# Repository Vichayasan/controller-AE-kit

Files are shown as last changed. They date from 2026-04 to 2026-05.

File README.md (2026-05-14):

# Controller AE Kit





---

## Table of Contents

1. [Project Introduction](#1-project-introduction)
2. [Project Objective](#2-project-objective)
3. [Background Theory: Acoustic Emission (AE) Sensing](#3-background-theory-acoustic-emission-ae-sensing)
4. [System Architecture](#4-system-architecture)
5. [Hardware List](#5-hardware-list)
6. [Design CAD](#6-design-CAD)
7. [Complete Wiring Diagram](#7-complete-wiring-diagram)
8. [Software Modules Explanation](#8-software-modules-explanation)
9. [Data Logging Output (CSV Format)](#9-data-logging-output-csv-format)
10. [Installation & Getting Started](#10-installation--getting-started)
11. [Project Timeline](#11-project-timeline)
12. [Timeline Summarize](#12-timeline-summarize)
13. [Contributors](#13-contributors)
14. [License & Ownership](#14-license--ownership)
15. [Note](#15-note)

---

## 1. Project Introduction

Mechanical seals are critical components widely used in rotating equipment such as pumps, compressors, and agitators within industrial facilities, particularly in the petrochemical and refinery sectors. Their primary function is to prevent the leakage of process fluids between the rotating shaft and the stationary housing, thereby ensuring safe and efficient plant operation.

Despite their essential role, mechanical seals are susceptible to progressive degradation caused by factors such as surface wear, thermal stress, chemical corrosion, and improper installation. When a seal begins to fail, microscopic cracks or surface discontinuities develop at the seal face, generating high-frequency elastic stress waves that propagate through the surrounding medium — a physical phenomenon known as Acoustic Emission (AE). If left undetected, even minor leakage can escalate into catastrophic failure, posing significant risks to personnel safety, environmental integrity, and equipment reliability.

This project presents the development of a real-time, embedded controller designed to acquire, process, and display Acoustic Emission signals originating from mechanical seal assemblies. The system is built upon the Cytron MOTION 2350 PRO microcontroller platform and is programmed entirely in MicroPython. It integrates a preamplified AE sensor, a graphical LCD display, a real-time clock (RTC) module, an encoder-based user interface, a buzzer alert system, and an RGB LED status indicator, forming a compact and self-contained condition monitoring kit suitable for field deployment.

---

## 2. Project Objective

The objectives of this project are as follows:

1. To develop a firmware-based embedded controller capable of acquiring Acoustic Emission signals from a mechanical seal assembly in real time.
2. To implement a signal processing pipeline in MicroPython that filters and evaluates AE signal amplitude against predefined threshold levels.
3. To design a user-friendly graphical interface on the MKS-MINI12864-V3 LCD display, allowing operators to monitor seal condition and configure detection parameters on-site.
4. To integrate a real-time clock (RTC) module for timestamping detection events, enabling traceability and post-incident analysis.
5. To provide audible and visual alert outputs — via a piezoelectric buzzer and NeoPixel RGB LED — to notify operators of abnormal AE activity indicative of seal leakage.
6. To validate the complete system through bench-level testing, verifying signal acquisition accuracy, threshold responsiveness, and display functionality.

---

## 3. Background Theory: Acoustic Emission (AE) Sensing

### 3.1 What is Acoustic Emission?

Acoustic Emission (AE) is a phenomenon in which transient elastic waves are generated by the rapid release of localized energy within a material. This energy release typically originates from micro-scale events such as crack initiation and propagation, plastic deformation, friction between sliding surfaces, impact, or fluid leakage through narrow gaps.

In the context of mechanical seal monitoring, AE signals are primarily produced by two mechanisms:

- **Solid-borne friction:** When the lapped faces of a degraded seal make irregular contact, micro-asperities on opposing surfaces collide and generate stress waves at frequencies typically ranging from **100 kHz to 1 MHz**.
- **Fluid-borne leakage:** When pressurized process fluid escapes through a compromised seal gap, turbulent flow and cavitation at the orifice generate broadband AE activity detectable at the seal housing.

Unlike vibration monitoring (which operates in the 10 Hz – 10 kHz range), AE sensing detects events at ultrasonic frequencies that are entirely inaudible to humans and undetectable by conventional accelerometers, making it uniquely sensitive to early-stage seal deterioration.

### 3.2 AE Signal Characteristics

A typical AE signal observed from a leaking mechanical seal exhibits the following characteristics:

| Parameter | Description |
|---|---|
| **Frequency Range** | 100 kHz – 1 MHz (ultrasonic) |
| **Signal Type** | Continuous or burst emission |
| **Key Feature** | Voltage amplitude correlates with leak severity |
| **Propagation** | Travels through solid structures as longitudinal or shear waves |

The most commonly used signal feature for leak detection is the voltage amplitude read from the preamplifier output, which represents the energy content of the AE signal at each sampling instant. An increase in amplitude beyond a calibrated threshold is a reliable indicator of abnormal friction or leakage activity at the seal face.

### 3.3 Preamplifier Role

Raw AE signals from piezoelectric sensors are extremely weak (typically in the microvolt range) and broadband. A dedicated **preamplifier** is therefore placed as close to the sensor as possible to:

1. Amplify the signal to a measurable voltage range (typically by 40–60 dB).
2. Apply bandpass filtering to reject low-frequency mechanical noise and retain only the AE frequency band of interest.
3. Improve the signal-to-noise ratio (SNR) before the signal is transmitted to the microcontroller's ADC input.

In this system, the preamplifier output is connected directly to an analog input pin of the MOTION 2350 PRO, where it is sampled and processed by the firmware.

---

## 4. System Architecture

The overall system consists of four functional layers: **sensing**, **processing**, **output/display**, and **user interaction**. The data flow is described as follows:

```
┌─────────────────────────────────────────────────────────────────┐
│                        SENSING LAYER                            │
│   AE Piezoelectric Sensor → Preamplifier (preamp_mod.py)        │
│   Analog signal → ADC on MOTION 2350 PRO (GP26, GP27)           │
└────────────────────────────┬────────────────────────────────────┘
                             │
┌────────────────────────────▼────────────────────────────────────┐
│                      PROCESSING LAYER                           │
│   config.py     → System-wide pin assignments and constants     │
│   preamp_mod.py → ADC sampling, circular buffer, waveform draw  │
│   rtc_mod.py    → Timestamp acquisition via DS3231 RTC          │
└────────┬───────────────────┬────────────────────────────────────┘
         │                   │
┌────────▼──────────┐  ┌─────▼──────────────────────────────────┐
│   OUTPUT LAYER    │  │           USER INTERFACE LAYER         │
│ beeper_mod.py     │  │  encoder_mod.py  → Rotary input        │
│ neopixel_mod.py   │  │  lcd_mod.py      → Graphical display   │
│ (buzzer + LED     │  │  ST7567driver.py → LCD low-level driver│
│  heartbeat)       │  │  (MKS-MINI12864-V3)                    │
└───────────────────┘  └────────────────────────────────────────┘
                                        │
                             ┌──────────▼──────────┐
                             │    SD CARD LOGGING  │
                             │  CSV file via SPI   │
                             │  (PIN_SD_CS = GP17) │
                             └─────────────────────┘
```

All modules are coordinated through `config.py`, which stores shared parameters such as ADC pin assignments, SPI/I2C settings, and timing constants, ensuring a clean and maintainable firmware architecture.

---

## 5. Hardware List

The following hardware components are used in this project:

| # | Component | Model | Role |
|---|---|---|---|
| 1 | Microcontroller | Cytron MOTION 2350 PRO | Main processing unit (RP2350 dual-core) |
| 2 | AE Sensor | Piezoelectric AE Sensor | Detects ultrasonic elastic waves from seal |
| 3 | Preamplifier | AE Preamplifier Module | Amplifies and filters raw AE signal |
| 4 | Graphical LCD | MKS-MINI12864-V3 (ST7567 driver) | Displays real-time waveform and UI |
| 5 | Real-Time Clock | DS3231 RTC Module | Provides accurate timestamp for CSV logging |
| 6 | Rotary Encoder | Incremental Encoder with button | User interface navigation |
| 7 | Buzzer | Piezoelectric Buzzer | Non-blocking audible feedback |
| 8 | RGB LED | NeoPixel WS2812B (×3) | Heartbeat and status indicator |
| 9 | SD Card Module | SPI SD Card | Stores CSV data log files |
| 10 | Power Supply | 5V DC / USB | Powers the controller board |

### Microcontroller: Cytron MOTION 2350 PRO

The Cytron MOTION 2350 PRO is a feature-rich robotics and automation controller based on the Raspberry Pi **RP2350** chip (dual-core Arm Cortex-M33, up to 150 MHz). It provides multiple GPIO pins, hardware I2C/SPI/UART interfaces, 12-bit ADC inputs, and native MicroPython support, making it well-suited for real-time embedded sensor applications.

> Reference: [Cytron MOTION 2350 PRO GitHub](https://github.com/CytronTechnologies/Cytron-MOTION-2350-PRO)

### Display: MKS-MINI12864-V3

The MKS-MINI12864-V3 is a compact 128×64 pixel graphical LCD module driven by the ST7567 controller chip, communicating via SPI. It provides a clear monochrome display sufficient for rendering real-time AE signal waveforms, voltage readouts, and menu navigation.

> Reference: [MKS-MINI12864-V3 GitHub](https://github.com/makerbase-mks/MKS-MINI12864-V3)

### RTC: DS3231

The DS3231 is a highly accurate I2C real-time clock module with a built-in temperature-compensated crystal oscillator (TCXO), ensuring timekeeping accuracy of ±2 ppm across a wide temperature range. It is used in this project to timestamp each CSV log entry, supporting post-analysis and maintenance record-keeping.

---
## 6. Design CAD

The mechanical enclosure of the Acoustic Emission (AE) Controller Kit was designed using 3D Computer-Aided Design (CAD) software to ensure durability, field-readiness, and ergonomic operation. The structural layout incorporates specific geometric features aimed at protecting internal components while facilitating user interaction and system maintenance.

### User Interface and Control Accessibility
* **LCD Display:** The enclosure features a flush-mounted rectangular cutout designed specifically for the LCD screen, allowing the display to align seamlessly with the exterior surface.
* **Rotary Encoder:** A dedicated aperture is provided for the rotary encoder knob, enabling precise parameter adjustments and system navigation.
* **Reset Button:** To facilitate system reboots, a precisely drilled hole allows direct access to the reset button.
* **Component Protection:** Recessed rectangular slots are engineered for both the main switch and the AMC channel ports, providing a physical buffer that mitigates the risk of accidental actuation or impact damage to the connectors.
* **Data Access:** An external rectangular port is integrated to permit SD card insertion and data retrieval without requiring the disassembly of the main housing.

### Structural Integrity and Assembly
* **Chassis Mounting:** To ensure structural rigidity, multiple mounting holes are distributed across the enclosure, utilizing heat-set threaded inserts to securely fasten the primary internal frame. Additional heat-set insert points are strategically positioned on both lateral sides to further reinforce the chassis assembly against operational vibrations.
* **Portability:** For enhanced portability and operational safety, specific holes equipped with heat-set inserts serve as secure anchor points for an external hand strap.

### Ergonomics and Power Management
* **Kickstand Integration:** The posterior section of the enclosure incorporates extruded housings and slotted grooves specifically designed to accommodate a deployable kickstand. This integration allows the device to be elevated at an optimal viewing angle during stationary operation.
* **Battery Retention:** The power management section features a dedicated rectangular cutout functioning as a battery locking mechanism. This is supplemented by elongated flat slots designed for routing cable ties or straps, ensuring the battery pack remains securely immobilized during field transit.





---
## 7. Complete Wiring Diagram

### AE Sensor Wiring

The AE sensor is connected to the preamplifier input, and the preamplifier analog output is routed to the ADC-capable GPIO pins on the MOTION 2350 PRO. The system supports **two independent AE sensors** simultaneously:

- **AE Sensor 01** → GP26 (`PIN_AE_SENSOR01_ADC`)
- **AE Sensor 02** → GP27 (`PIN_AE_SENSOR02_ADC`)

- Hardware connection wiring — **AE sensor**


### MKS-MINI12864-V3 to MOTION 2350 PRO GPIO Pinout

The LCD and SD card share the same SPI bus. The following pin mapping is used:

| Signal | MOTION 2350 PRO GPIO | Description |
|---|---|---|
| SPI SCK | GP18 | SPI Clock (LCD + SD card shared) |
| SPI MOSI | GP19 | SPI Data out |
| SPI MISO | GP16 | SPI Data in (SD card read) |
| LCD CS | GP2 | LCD Chip Select |
| LCD DC | GP3 | LCD Data/Command Select |
| LCD RST | GP1 | LCD Reset |
| SD CS | GP17 | SD Card Chip Select |
| RTC SDA | GP28 | RTC I2C Data |
| RTC SCL | GP29 | RTC I2C Clock |
| NeoPixel | GP4 | RGB LED Data |
| Buzzer | GP0 | PWM Buzzer |
| Encoder A | GP5 | Encoder Channel A |
| Encoder B | GP6 | Encoder Channel B |
| Encoder BTN | GP7 | Encoder Push-Button |

> **Note:** All pin assignments above are defined in `config.py`. Verify against your specific board revision before assembly.

- Hardware connection — **MKS-MINI12864-V3** Pin to **MOTION 2350 PRO** GPIO


---

## 8. Software Modules Explanation

This repository contains the following MicroPython source files. Each module has a single, well-defined responsibility following a modular firmware design pattern.

---

### `config.py` — System-Wide Pin and Hardware Constants

**Purpose:** Acts as the single source of truth for all hardware pin assignments and communication parameters. Every other module imports `config` directly, ensuring that changing a physical wire connection requires editing only this one file.

**Complete pin definitions:**

```python
# config.py - PIN and hardware constants

PIN_NEOPIXEL = 4          # NeoPixel RGB LED data pin
PIN_BEEPER   = 0          # Piezoelectric buzzer PWM pin

PIN_ENC_A    = 5          # Rotary encoder channel A
PIN_ENC_B    = 6          # Rotary encoder channel B
PIN_ENC_BTN  = 7          # Rotary encoder push-button

PIN_LCD_CS   = 2          # LCD SPI chip select
PIN_LCD_DC   = 3          # LCD data/command select
PIN_LCD_RST  = 1          # LCD reset

PIN_SPI_SCK  = 18         # SPI clock (shared: LCD + SD card)
PIN_SPI_MOSI = 19         # SPI MOSI
PIN_SPI_MISO = 16         # SPI MISO
PIN_SD_CS    = 17         # SD card chip select

PIN_AE_SENSOR01_ADC = 26  # AE Sensor 1 analog input
PIN_AE_SENSOR02_ADC = 27  # AE Sensor 2 analog input

PIN_RTC_SDA  = 28         # RTC I2C data
PIN_RTC_SCL  = 29         # RTC I2C clock

LCD_BAUD = 2_000_000      # SPI baud rate for LCD (2 MHz)
SD_BAUD  =    50_000      # SPI baud rate for SD card (50 kHz)

VREF = 3.3                # ADC reference voltage (Volts)
```

> **Key design note:** The system supports **two independent AE sensors simultaneously** (`AE01` on GP26, `AE02` on GP27). A third sensor channel is already commented out in the code and can be enabled by adding a single line.

---

### `preamp_mod.py` — Multi-Sensor AE Signal Acquisition and Waveform Display

**Purpose:** Defines the `AESensor` class, which manages ADC sampling, circular buffer storage, and real-time waveform rendering on the LCD for each AE sensor independently. Two sensor instances (`AE01` and `AE02`) are created at module level and shared across the application.

**Key class: `AESensor`**

Each `AESensor` instance maintains its own completely isolated state, including its own sample buffer, timing counters, and display timing — ensuring that two sensors can operate simultaneously without any shared state conflicts.

| Parameter | Default | Description |
|---|---|---|
| `buffer_size` | 128 | Number of samples in circular buffer (matches LCD width) |
| `sample_ms` | 20 ms | Sampling interval (50 Hz effective sample rate) |
| `draw_ms` | 80 ms | Minimum time between LCD redraws (~12.5 fps) |

**How it works:**

1. `read_and_add()` — reads the ADC (`read_u16()`, 16-bit unsigned, range 0–65535) and stores the raw value into a circular buffer, advancing the write index on each call.
2. `get_ordered_buffer()` — reconstructs the buffer in chronological order by concatenating the two halves of the circular array around the current write index.
3. `draw_screen()` — converts each buffer value to a unit float `[0.0, 1.0]`, maps it to a pixel Y-coordinate within a 40-pixel tall plot area, and draws a connected line trace across all 128 columns of the LCD. The current voltage and logging status (`LOG: Y/N`) are shown as a text overlay.
4. `raw_to_v(raw)` — converts a raw 16-bit ADC reading to voltage:

   **V = raw × VREF / 65535 = raw × 3.3 / 65535**

**Sensor instances created at module level:**

```python
sensors = {
    'AE01': AESensor(config.PIN_AE_SENSOR01_ADC, name="AE SENSOR 01"),
    'AE02': AESensor(config.PIN_AE_SENSOR02_ADC, name="AE SENSOR 02"),
}
```

The helper function `get_sensor(name)` allows the main application to retrieve a sensor object by name string (e.g., `get_sensor('AE01')`).

---

### `encoder_mod.py` — Rotary Encoder with Quadrature Decoding and Long Press

**Purpose:** Reads the rotary encoder's two quadrature channels (A and B) and its push-button, decoding physical rotation into signed click counts and classifying button presses as either short press or long press. All state is maintained as module-level globals and updated by calling `update()` from the main loop.

**Quadrature decoding — state machine:**

The encoder state is represented as a 2-bit value `(A << 1) | B`. Valid transitions between states are encoded in a lookup table `TRANS`, which maps each `(old_state, new_state)` pair to a direction value of `+1` or `-1`. Invalid transitions (caused by noise or contact bounce) produce `0` and are silently ignored.

```python
TRANS = {
    (0,1):+1, (1,3):+1, (3,2):+1, (2,0):+1,   # clockwise
    (0,2):-1, (2,3):-1, (3,1):-1, (1,0):-1,   # counter-clockwise
}
STEPS_PER_CLICK = 4   # 4 state transitions = 1 detent click
```

**Timing constants:**

| Constant | Value | Description |
|---|---|---|
| `DEBOUNCE_MS` | 30 ms | Button debounce window |
| `LONG_MS` | 700 ms | Hold duration to trigger long press |
| `ENC_IGNORE_MS` | 150 ms | Encoder ignored immediately after button press |

**Public interface (call from main loop):**

```python
encoder_mod.update()                    # must be called every loop iteration
delta   = encoder_mod.pop_delta()       # net clicks since last call (+/-)
pressed = encoder_mod.pop_pressed()     # True if short press occurred
long    = encoder_mod.pop_long()        # True if long press occurred
```

Each `pop_*` function reads and atomically clears its flag, preventing double-reads.

---

### `beeper_mod.py` — Non-Blocking PWM Buzzer

**Purpose:** Drives the piezoelectric buzzer via hardware PWM in a completely non-blocking manner. The buzzer is activated for a fixed duration and then silenced automatically by polling `beep_update()` in the main loop — no `sleep()` or blocking delay is used at any point.

**How it works:**

```python
beep_start(freq=900, ms=60)   # begin a 60 ms beep at 900 Hz
beep_update()                 # call every loop — silences buzzer when timer expires
```

`beep_start()` sets the PWM frequency and duty cycle, then records a deadline timestamp using `time.ticks_add()`. On each call to `beep_update()`, the current time is compared against the deadline; when reached, the duty cycle is set to zero (silence).

**Key constants:**

| Constant | Value | Description |
|---|---|---|
| `BEEP_DUTY` | 45000 | Standard beep duty cycle (~69% of 65535) |
| `PRESS_DUTY` | 65535 | Full duty cycle for key-press confirmation tone |

---

### `neopixel_mod.py` — NeoPixel RGB LED Indicator

**Purpose:** Controls a strip of 3 WS2812B NeoPixel LEDs connected to `config.PIN_NEOPIXEL` (GP4). On startup the LEDs are initialised to green. The module provides a `toggle()` function to blink the green LED on and off, used by the main application as a **heartbeat indicator** to confirm the firmware loop is running correctly.

**Key details:**

- The WS2812B protocol transmits colour in **GRB order** (not RGB), handled internally: `np[i] = (g, r, b)`.
- **3 LEDs** (`NPIX = 3`) are all driven to the same colour simultaneously.
- The `import neopixel` is wrapped in `try/except ImportError`, so the module degrades gracefully to a no-op if the driver is unavailable.

```python
leds_rgb(r, g, b)   # set all 3 LEDs to an RGB colour (0–255 each)
toggle()            # toggle green LED on/off (heartbeat blink)
```

**Default startup state:** `LED_G = 80` → all LEDs glow green at brightness 80/255.

---

### `rtc_mod.py` — Real-Time Clock Interface (DS3231)

**Purpose:** Provides a robust, fault-tolerant interface for reading the current date and time from the DS3231 RTC module over I2C (GP28/GP29). It performs I2C bus scanning, verifies the DS3231 is present at address `0x68`, and exposes two formatted string functions used throughout the application.

**Key functions:**

```python
rtc_init()       # initialize I2C bus and verify DS3231; returns True/False
time_string()    # returns "YYYY-MM-DD HH:MM:SS"  ← used in CSV logging
time_hms()       # returns "HH:MM:SS"             ← used in LCD display
```

The module handles all exceptions internally and sets `rtc_ok = False` if initialization fails, allowing the application to continue operating without a connected RTC (timestamps will display `RTC_READ_FAIL`).

**Dependency:** Relies on `DS3231.py` for low-level I2C register communication.

---

### `DS3231.py` — DS3231 Low-Level I2C Driver

**Purpose:** Implements the low-level I2C register read/write operations for the DS3231 chip, including Binary-Coded Decimal (BCD) conversion between the chip's internal register format and human-readable time values. This file is a hardware driver and is accessed only through `rtc_mod.py`.

---

### `lcd_mod.py` and `ST7567driver.py` — LCD Display Stack

**`ST7567driver.py`** implements the SPI communication protocol for the ST7567 LCD controller, handling the initialization sequence, page/column addressing, and raw framebuffer writes at 2 MHz (`config.LCD_BAUD`).

**`lcd_mod.py`** builds on top of the driver and exposes higher-level drawing primitives (`text`, `fill_rect`, `pixel`, `lcd_update`) used by `preamp_mod.py` to render the waveform trace and status text overlay. The LCD communicates via the shared SPI bus (GP18/GP19) with chip-select on GP2.

---

## 9. Data Logging Output (CSV Format)

When logging is enabled by the operator via the rotary encoder menu — indicated by `LOG: Y` on the LCD display — the system continuously writes AE measurement data from both sensors to the SD card in CSV format. The SD card is accessed via the shared SPI bus at `config.SD_BAUD` (50 kHz), with chip-select on `PIN_SD_CS` (GP17).

The logged CSV file can be retrieved by removing the SD card and opening it on any computer using spreadsheet software such as Microsoft Excel or Google Sheets.

### CSV Column Structure

Each row in the CSV file contains **six columns** representing both AE sensor channels recorded at the same sampling instant.

Output data=


| Column | Content | Unit | Example |
|---|---|---|---|
| 1 | Timestamp — AE Sensor 01 | `D/M/YY HH:MM` from DS3231 | `8/5/26 16:12` |
| 2 | Raw ADC value — AE Sensor 01 (GP26) | Integer, 0–65535 | `528` |
| 3 | Converted voltage — AE Sensor 01 | Volts (V) | `0.0266` |
| 4 | Timestamp — AE Sensor 02 | `D/M/YY HH:MM` from DS3231 | `8/5/26 16:12` |
| 5 | Raw ADC value — AE Sensor 02 (GP27) | Integer, 0–65535 | `608` |
| 6 | Converted voltage — AE Sensor 02 | Volts (V) | `0.0306` |

### Voltage Conversion Formula

The voltage value in columns 3 and 6 is derived directly from `preamp_mod.raw_to_v()`:

```
V = raw_adc × VREF / 65535
V = raw_adc × 3.3  / 65535
```

**Verification examples from the logged data:**

```
Raw =  528  →  528  × 3.3 / 65535 = 0.0266 V  ✓
Raw =  608  →  608  × 3.3 / 65535 = 0.0306 V  ✓
Raw =  672  →  672  × 3.3 / 65535 = 0.0338 V  ✓
```

### Interpreting the Logged Data

- **Normal baseline:** Under no-leak conditions, voltage values from the preamplifier output typically remain in the range of **0.020 – 0.035 V**, reflecting only ambient electrical noise and mechanical background activity.

- **Elevated reading:** A sustained rise in voltage above the established baseline indicates increasing AE activity at the seal face. This may be caused by progressive seal face wear, lubrication breakdown, or early-stage leakage and warrants closer inspection.

- **Transient spike (outlier):** A single sample significantly higher than surrounding values — such as a reading of **0.8306 V** occurring among a sequence of ~0.030 V readings — may indicate a discrete AE burst event caused by a sudden crack propagation, impact, or fluid jet. Such spikes should be noted and reviewed in the context of adjacent samples rather than treated as sustained leakage.

### Notes on Timestamp Resolution

The DS3231 RTC provides timestamps at **one-second resolution**. Since the ADC sampling interval is 20 ms (50 Hz), multiple rows within the same CSV file will share identical timestamp values (e.g., `8/5/26 16:12`). This is expected behaviour and does not indicate duplicate entries. For sub-second time resolution, the sample index within each second can be inferred from the row order.

---

## 10. Installation & Getting Started

### Prerequisites

Ensure the following are available before proceeding:

- **Hardware:** Assembled controller kit with all components connected as per the wiring diagram in Section 6.
- **Software:** [Thonny IDE](https://thonny.org/) (recommended) or any MicroPython-compatible editor.
- **Firmware:** MicroPython firmware flashed onto the MOTION 2350 PRO board.

### Step 1 — Flash MicroPython onto MOTION 2350 PRO

1. Download the latest MicroPython `.uf2` firmware for RP2350 from the [official MicroPython website](https://micropython.org/download/).
2. Hold the **BOOT** button on the MOTION 2350 PRO, then connect it to your PC via USB.
3. The board will appear as a USB mass storage device (e.g., `RPI-RP2`).
4. Drag and drop the `.uf2` firmware file onto the drive.
5. The board will reboot automatically with MicroPython installed.

### Step 2 — Clone this Repository

```bash
git clone https://github.com/Vichayasan/controller-AE-kit.git
```

### Step 3 — Upload Files to the Board

Using Thonny IDE or `mpremote`:

1. Open Thonny IDE and connect to the MOTION 2350 PRO via the correct COM port.
2. Upload **all `.py` files** from this repository to the root directory of the board's filesystem.

   The required files are:
   ```
   config.py
   DS3231.py
   ST7567driver.py
   preamp_mod.py
   rtc_mod.py
   lcd_mod.py
   encoder_mod.py
   beeper_mod.py
   neopixel_mod.py
   main.py
   ```

### Step 4 — Configure Parameters

Open `config.py` and verify the following settings match your hardware setup:

```python
PIN_AE_SENSOR01_ADC = 26   # GPIO pin for AE Sensor 01
PIN_AE_SENSOR02_ADC = 27   # GPIO pin for AE Sensor 02
PIN_RTC_SDA         = 28   # RTC I2C SDA
PIN_RTC_SCL         = 29   # RTC I2C SCL
VREF                = 3.3  # ADC reference voltage (Volts)
```

> **Important:** Before deployment, record the baseline voltage of each sensor under known no-leak conditions. Use this baseline to calibrate the detection threshold in the main application. A threshold set approximately 20–30% above the measured baseline is recommended as a starting point.

### Step 5 — Run the System

1. Reset the board or press the **RUN** button in Thonny.
2. The LCD will display the initialization screen, followed by the real-time AE waveform display.
3. Rotate the encoder to switch between AE Sensor 01 and AE Sensor 02 views.
4. Press the encoder button to toggle data logging (`LOG: Y/N`).
5. The NeoPixel LEDs will blink green as a heartbeat indicator during normal operation.
6. When logging is active (`LOG: Y`), sensor data is written continuously to the SD card in CSV format as described in Section 8.

---

## 11. Project Timeline


---

## 12. timeline summarize
The development of the Mechanical Seal Leak Detection system spans from late January to early May. The project we kicks off with sensor and microcontroller testing in late January. February and March serve as the core engineering phase, featuring parallel tracks for hardware design (progressing from CAD and wiring diagrams to multiple prototype iterations) and software development (covering requirements, signal coding, and interface design). Comprehensive system testing begins in late March alongside signal verification and continues throughout April. The timeline culminates in a dedicated period for final bug resolutions and project reporting in May.

---

## 13.Contributors
- Ratthawat Unakanporn : Validate Sensor and Wiring
  - Email: ratthawatu@gmail.com
  
- Chaiwat Phuchaiyanon  : Package Design/Report writing
  - Email: chaiwat.phuchaiyanon@gmail.com
  
- Wachirawit Kruawan  : Package Design
  - Email: Nine7465@gmail.com
    
- Vichayasan Sreshthaputra : Firmware design/Report writing
  - Email: sreshthaputrav@gmail.com 

---

Department of Mechanical Engineering, Faculty of Engineering, Chulalongkorn University</br>
## 14. License & Ownership
This repository contains proprietary source code. All code in this repository is the intellectual property of Rayong Engineering & Plant Service Co.,Ltd. and Chulalongkorn University

Unauthorized use, reproduction, or distribution of this code is strictly prohibited.

---

## 15. NOTE
- MKS-MINI12864-V3: https://github.com/makerbase-mks/MKS-MINI12864-V3
- MOTION 2350 PRO: https://github.com/CytronTechnologies/Cytron-MOTION-2350-PRO

## 16.Video Showcase
- Casing

<video src="https://github.com/user-attachments/assets/0c8ebab6-43b8-4860-899b-3834f37bed8a" autoplay loop muted playsinline width="100%"></video>

- Firmware

<video src="https://github.com/user-attachments/assets/b9758f13-1c47-428d-a448-221c20fe1263" autoplay loop muted playsinline width="100%"></video>

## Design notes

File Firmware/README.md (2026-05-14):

# REPCO AE Recorder Firmware

MicroPython firmware for an RP2350 controller with an MKS MINI12864 V3 display/SD peripheral.

## Hardware

- Controller: Cytron MOTION 2350 Pro / RP2350
- Display/SD peripheral: MKS MINI12864 V3
- RTC: DS3231
- AE analog inputs:
  - Ambient: GPIO26 / ADC0
  - Machine: GPIO27 / ADC1

## Boot Flow

1. Show startup logo silently.
2. Set up SD card with 5 retry attempts.
3. If SD setup fails, choose `Restart` or `Format SD`.
4. Show date/time setup using DS3231.
5. Show `AE is Recording`.
6. Enter main menu and log AE data to CSV.

## CSV Log

Default log file:

```text
/sd/ae_record.csv
```

CSV columns:

```text
timestamp_machine,raw_machine,volt_machine,timestamp_ambient,raw_ambient,volt_ambient
```

## Upload To Board

Copy all `.py` files in this folder to the MicroPython board root.

The boot file is:

```text
main.py
```

## Notes

- LCD and SD card share SPI. The firmware switches chip-select and SPI speed before each operation.
- Logo and SD setup screens are silent.
- Encoder rotation/press sounds can be toggled in the Setting menu.
- SD card status is shown as `OK`, `FAIL`, or `FULL`.

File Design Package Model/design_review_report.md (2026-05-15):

# รายงานการรีวิวดีไซน์: Enclosure Concept Design

## ภาพรวม

รายงานนี้บันทึกความคืบหน้าและการอัปเดตของโปรเจกต์กล่อง 3D Print ทั้งสองรุ่น รวมถึงปัญหาที่พบและการแก้ไขชิ้นส่วนต่างๆ

---

## Concept Design ที่ 1

### สรุป
- ปริ้นกล่องออกมาเรียบร้อย และยืนยันได้ว่าอุปกรณ์เบื้องต้นใส่ได้ตามที่คำนวณไว้
- ประกอบอุปกรณ์หลักเบื้องต้นได้สำเร็จ

### ปัญหาและการแก้ไขเบื้องต้น
- บางชิ้นส่วนต้องมีการตัดเพิ่มเติมหลังปริ้น เพื่อแก้ไขการใช้งานเบื้องต้น

### ชิ้นส่วนที่มีการแก้ไข

#### 1. Middle Base V1
- **ขยายรู** — ขยายรูยึด/รูเข้าถึงให้ใหญ่ขึ้น เพื่อให้ใช้งานและเข้าถึงอุปกรณ์ได้ง่ายขึ้น

#### 2. Base V1
- **แก้ระยะ AE Sensor** — ปรับขนาดช่องให้ AE Sensor พอดีกับช่องที่กำหนด

#### 3. Middle Base V1 (การไขน็อต)
- **เข้าถึงน็อตได้ง่ายขึ้น** — ปรับดีไซน์เพื่อให้ไขและถอดน็อตได้สะดวกขึ้น ช่วยให้แยกชั้น **Chassis Middle** และ **Lower Base** ได้ง่ายขึ้น

#### 4. ชิ้นส่วนกลาง (ด้านบน)
- **เพิ่มรูถอดน็อตด้านบน** — เจาะรูด้านบนเพื่อให้ถอดน็อตในชิ้นกลางออกได้ง่ายขึ้น
- **เพิ่มช่อง Metal Plate** — เพิ่มช่องสำหรับเสียบ Metal Plate แบบถอดเปลี่ยนได้ เพื่อรองรับการต่อ Channel หรือ Switch ต่างๆ ในอนาคต

---

## Concept Design ที่ 2

### สรุป
นำชิ้นส่วนจาก Design ที่ 1 มาปรับแก้และเพิ่มชิ้นส่วนใหม่ เพื่อรองรับการพัฒนาในอนาคต

### ชิ้นส่วนที่อัปเดต

| ชิ้นส่วน | เวอร์ชัน | หมายเหตุ |
|---|---|---|
| Base | v1.2 | ปรับปรุงจาก Base v1 |
| Metal Plate Swap | — | แผ่นสำหรับถอดเปลี่ยนได้ |
| Middle Base | V1.2 | ปรับปรุงจาก Middle Base V1 |
| RP 2350 with Brass Pole | — | ชิ้นส่วนยึด Microcontroller |
| Upper Base | v1.2 | ปรับปรุงจาก Upper Base v1 |

### การปรับปรุงหลัก

#### ระบบ Metal Plate Swap
- เพิ่มระบบ **Metal Plate แบบถอดเปลี่ยนได้** เพื่อรองรับการปรับเปลี่ยนในอนาคต
- ออกแบบให้ยืดหยุ่น: สามารถเปลี่ยนแผ่นได้ตาม **Channel หรือ Switch** ที่ต้องการ
- มองเห็นแนวทางในการพัฒนาเป็น **แผ่นโลหะจริง** เพื่อเพิ่มความทนทานและประสิทธิภาพมากกว่าพลาสติก PLA

#### ช่องใส่ Power Supply (Base v1.2)
- ปรับช่องเล็กน้อยเพื่อให้ **ร้อย Cable Tie ได้ง่ายขึ้น**
- แก้ไขปัญหาคุณภาพการปริ้นที่ไม่ดีจากรอบแรก

#### หน้าจอแสดงสถานะแบตเตอรี่
- เพิ่มช่องสำหรับ **หน้าจอแสดงสถานะแบตเตอรี่** บนฝาด้านบน
- การแสดงผลขึ้นอยู่กับ Power Supply ที่ใช้งาน

#### ช่อง SD Card
- ปรับช่อง SD Card ให้ **ใส่และถอดได้ง่ายขึ้น** ระหว่างการพัฒนา
- ออกแบบให้ปรับเปลี่ยนได้ตามความต้องการในอนาคต

#### Middle Base V1.2 — ช่องวงจรและแผงด้านข้าง
- ปรับขนาดช่องภายในให้รองรับแผงวงจรได้ดีขึ้น
- เพิ่ม **ช่องด้านข้างแบบถอดเปลี่ยนได้** สำหรับติดตั้ง Switch ต่างๆ
- สามารถปรับ Layout ในอนาคตให้ Compact และสอดคล้องกับอุปกรณ์ที่จะใส่ในกล่อง

---

## ผลลัพธ์หลังปริ้น: Concept Design ที่ 2

ชิ้นส่วนหลักที่ปริ้นสำเร็จในรอบที่สอง:

- **Upper Base v1.2** — ฝาด้านบนพร้อมช่องหน้าจอและช่อง SD Card
- **Base v1.2** — ถาดล่างพร้อม Layout ช่องใส่อุปกรณ์และ Brass Pole
- **Middle Base V1.2** — โครงกลางพร้อมช่อง Switch ด้านข้างและช่องวางวงจร

---

## แนวทางการพัฒนาในอนาคต

- สามารถปรับ Layout และตำแหน่งช่องต่างๆ ให้เหมาะกับอุปกรณ์ใหม่ได้
- ระบบ Metal Plate Swap ช่วยให้เปลี่ยนแผง Switch และ Channel ได้โดยไม่ต้องออกแบบใหม่ทั้งหมด
- วางแผนเปลี่ยนชิ้นส่วนโครงสร้างหลักเป็น **แผ่นโลหะ** เพื่อเพิ่มความแข็งแรงและอายุการใช้งาน
- ช่องต่อประสาน (SD Card, หน้าจอ, Switch) ออกแบบมาให้รองรับการพัฒนาต่อในอนาคต

---

*รายงานนี้จัดทำจากเอกสารรีวิวดีไซน์ภายใน — Concept Design ที่ 1 และ 2*

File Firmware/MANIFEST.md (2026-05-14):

# Firmware File Manifest

## Board Files

- `main.py` - main app and firmware flow
- `config.py` - pin map and hardware constants
- `lcd_mod.py` - ST7567 LCD and shared SPI management
- `ST7567driver.py` - LCD driver
- `sd_utils.py` - SD card SPI driver, mount, format, retry handling
- `rtc_mod.py` - RTC wrapper
- `DS3231.py` - DS3231 library
- `encoder_mod.py` - rotary encoder and button input
- `beeper_mod.py` - PWM beeper with ON/OFF control
- `neopixel_mod.py` - NeoPixel ON/OFF control
- `preamp_mod.py` - AE sensor sampling and waveform drawing
- `logo_mod.py` - startup logo rendering

## Documentation / Assets

- `firmware_flow_chart.png` - system firmware flow chart
- `assets/logo.png` - source logo image
- `assets/logo.c` - source RGB565 logo conversion

## Generated / Excluded

Do not commit local board pull-back files such as:

- `com18_uploaded_*.py`
- `__pycache__/`
- editor or virtual environment folders

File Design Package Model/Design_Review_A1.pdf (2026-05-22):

Enclosure Concept Design
Design Review Report

ภาพรวม

รายงานนี้บันทึกความคืบหน้าและการอัปเดตของโปรเจกต์กล่อง 3D Print ทั้งสองรุ่น รวมถึงปัญหาที่พบและการแก้ไขชิ้นส่วนต่างๆ

Concept Design ที่ 1

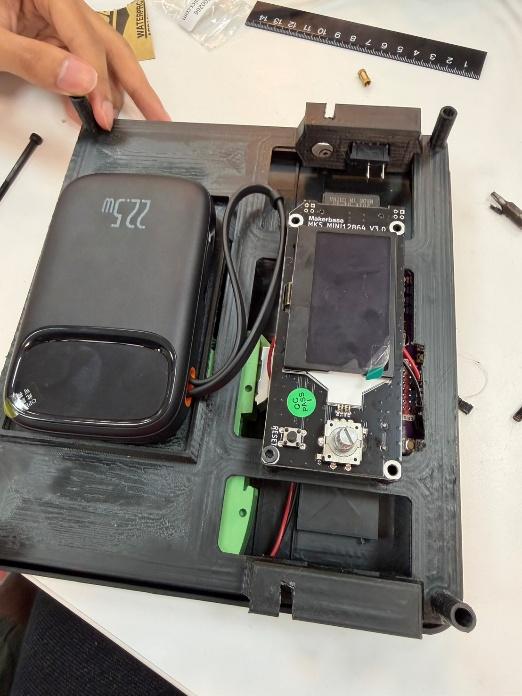
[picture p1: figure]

สรุป

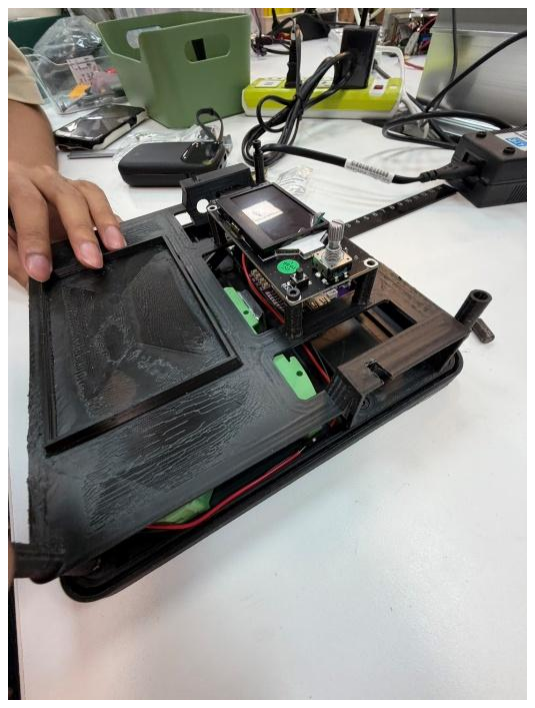
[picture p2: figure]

- ปริ้นกล่องออกมาเรียบร้อย และยืนยันได้ว่าอุปกรณ์เบื้องต้นใส่ได้ตามที่คำนวณไว้
- ประกอบอุปกรณ์หลักเบื้องต้นได้สำเร็จ
ปัญหาและการแก้ไขเบื้องต้น
- บางชิ้นส่วนต้องมีการตัดเพิ่มเติมหลังปริ้น เพื่อแก้ไขการใช้งานเบื้องต้น
- สายไฟที่แน่นกันจนไม่สามารถต่อได้
- การปริ้น 3D บาง part พื้นผิวมีปัญหาทำให้บางชิ้นส่วนแตกหักง่าย

ชิ้นส่วนที่มีการแก้ไข

### 1. Middle Base V1 — ขยายรู

- ขยายรูยึด/รูเข้าถึงให้ใหญ่ขึ้น เพื่อให้ใช้งานและเข้าถึงอุปกรณ์ได้ง่ายขึ้น

### 2. Base V1 — แก้ระยะ AE Sensor

- ปรับขนาดช่องให้ AE Sensor พอดีกับช่องที่กำหนด

### 3. Middle Base V1 — การไขน็อต

- ปรับดีไซน์เพื่อให้ไขและถอดน็อตได้สะดวกขึ้น
- ช่วยให้แยกชั้น Chassis Middle และ Lower Base ได้ง่ายขึ้น

### 4. ชิ้นส่วนกลาง (ด้านบน)

- เพิ่มรูด้านบนเพื่อให้ถอดน็อตในชิ้นกลางออกได้ง่ายขึ้น
- เพิ่มช่อง Metal Plate แบบถอดเปลี่ยนได้ เพื่อรองรับการต่อ Channel หรือ Switch ต่างๆ ในอนาคต

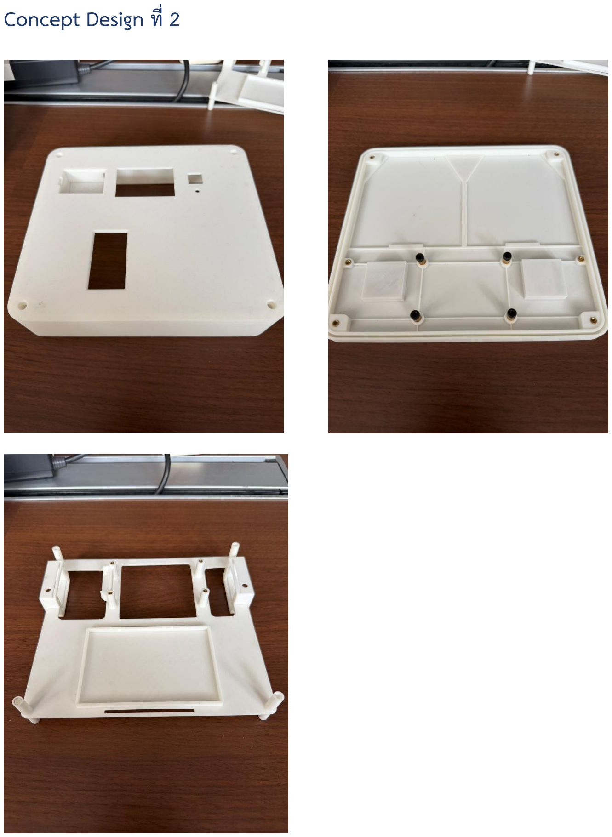
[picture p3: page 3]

Concept Design ที่ 2

สรุป
นำชิ้นส่วนจาก Design ที่ 1 มาปรับแก้และเพิ่มชิ้นส่วนใหม่ เพื่อรองรับการพัฒนาในอนาคต

ชิ้นส่วนที่อัปเดต
ชิ้นส่วน | เวอร์ชัน | หมายเหตุ
Base | v1.2 | ปรับปรุงจาก Base v1
Metal Plate Swap | — | แผ่นสำหรับถอดเปลี่ยนได้
Middle Base | V1.2 | ปรับปรุงจาก Middle Base V1
RP 2350 with Brass Pole | — | ชิ้นส่วนยึด Microcontroller
Upper Base | v1.2 | ปรับปรุงจาก Upper Base v1

การปรับปรุงหลัก
ระบบ Metal Plate Swap
- เพิ่มระบบ Metal Plate3d printแบบถอดเปลี่ยนได้เพื่อรองรับการปรับเปลี่ยนในอนาคต ในอนาคตอาจจะสามารถเปลี่ยนวัสดุปริ้นตามต้องการ
- ออกแบบให้ยืดหยุ่น: สามารถเปลี่ยนแผ่นได้ตาม Channel หรือ Switch ที่ต้องการ
- มองเห็นแนวทางในการพัฒนาเป็นแผ่นโลหะจริง เพื่อเพิ่มความทนทานและประสิทธิภาพมากกว่าพลาสติก PLA

ช่องใส่ Power Supply (Base v1.2)
- ปรับช่องเล็กน้อยเพื่อให้ร้อย Cable Tie ได้ง่ายขึ้น
- แก้ไขปัญหาคุณภาพการปริ้นที่ไม่ดีจากรอบแรก

หน้าจอแสดงสถานะแบตเตอรี่
- เพิ่มช่องสำหรับหน้าจอแสดงสถานะแบตเตอรี่บนฝาด้านบน
- การแสดงผลขึ้นอยู่กับ Power Supply ที่ใช้งาน

ช่อง SD Card
- ปรับช่อง SD Card ให้ใส่และถอดได้ง่ายขึ้นระหว่างการพัฒนา
- ออกแบบให้ปรับเปลี่ยนได้ตามความต้องการในอนาคต

Middle Base V1.2 — ช่องวงจรและแผงด้านข้าง
- ปรับขนาดช่องภายในให้รองรับแผงวงจรได้ดีขึ้น
- เพิ่มช่องด้านข้างแบบถอดเปลี่ยนได้สำหรับติดตั้ง Switch ต่างๆ
- สามารถปรับ Layout ในอนาคตให้ Compact และสอดคล้องกับอุปกรณ์ที่จะใส่ในกล่อง

ผลลัพธ์หลังปริ้น: Concept Design ที่ 2

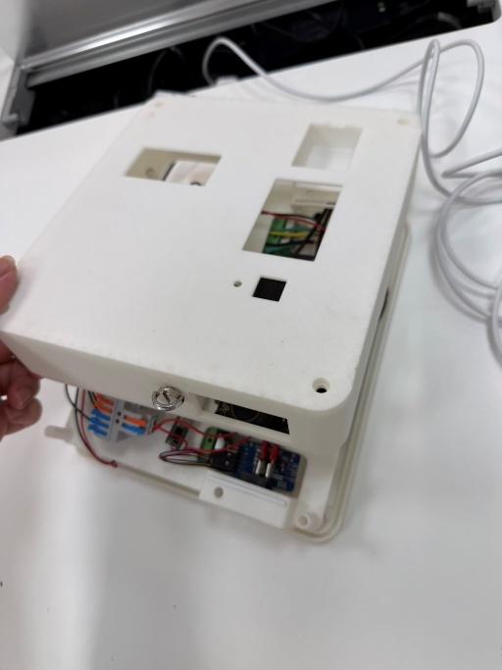
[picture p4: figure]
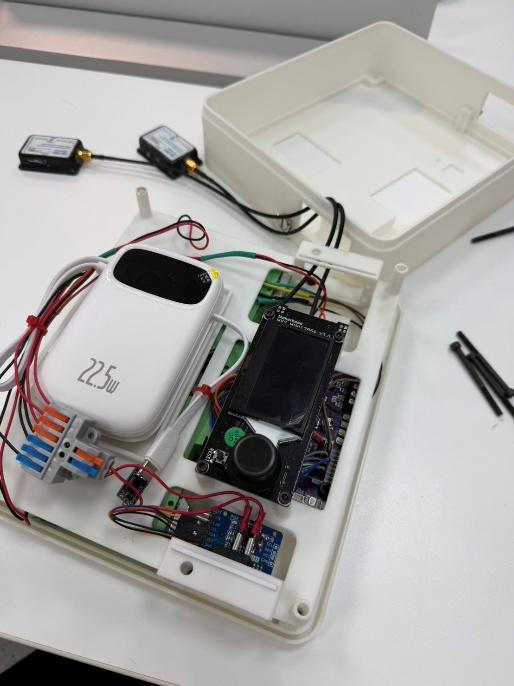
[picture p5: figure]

- Upper Base v1.2 — ฝาด้านบนพร้อมช่องหน้าจอและช่อง SD Card
- Base v1.2 — ถาดล่างพร้อม Layout ช่องใส่อุปกรณ์และ Brass Pole
- Middle Base V1.2 — โครงกลางพร้อมช่อง Switch ด้านข้างและช่องวางวงจร

แนวทางการพัฒนาในอนาคต

- สามารถปรับ Layout และตำแหน่งช่องต่างๆ ให้เหมาะกับอุปกรณ์ใหม่ได้
- ระบบ Metal Plate Swap ช่วยให้เปลี่ยนแผง Switch และ Channel ได้โดยไม่ต้องออกแบบใหม่ทั้งหมด
- วางแผนเปลี่ยนชิ้นส่วนโครงสร้างหลักเป็นแผ่นโลหะ เพื่อเพิ่มความแข็งแรงและอายุการใช้งาน
- ช่องต่อประสาน (SD Card, หน้าจอ, Switch) ออกแบบมาให้รองรับการพัฒนาต่อในอนาคต

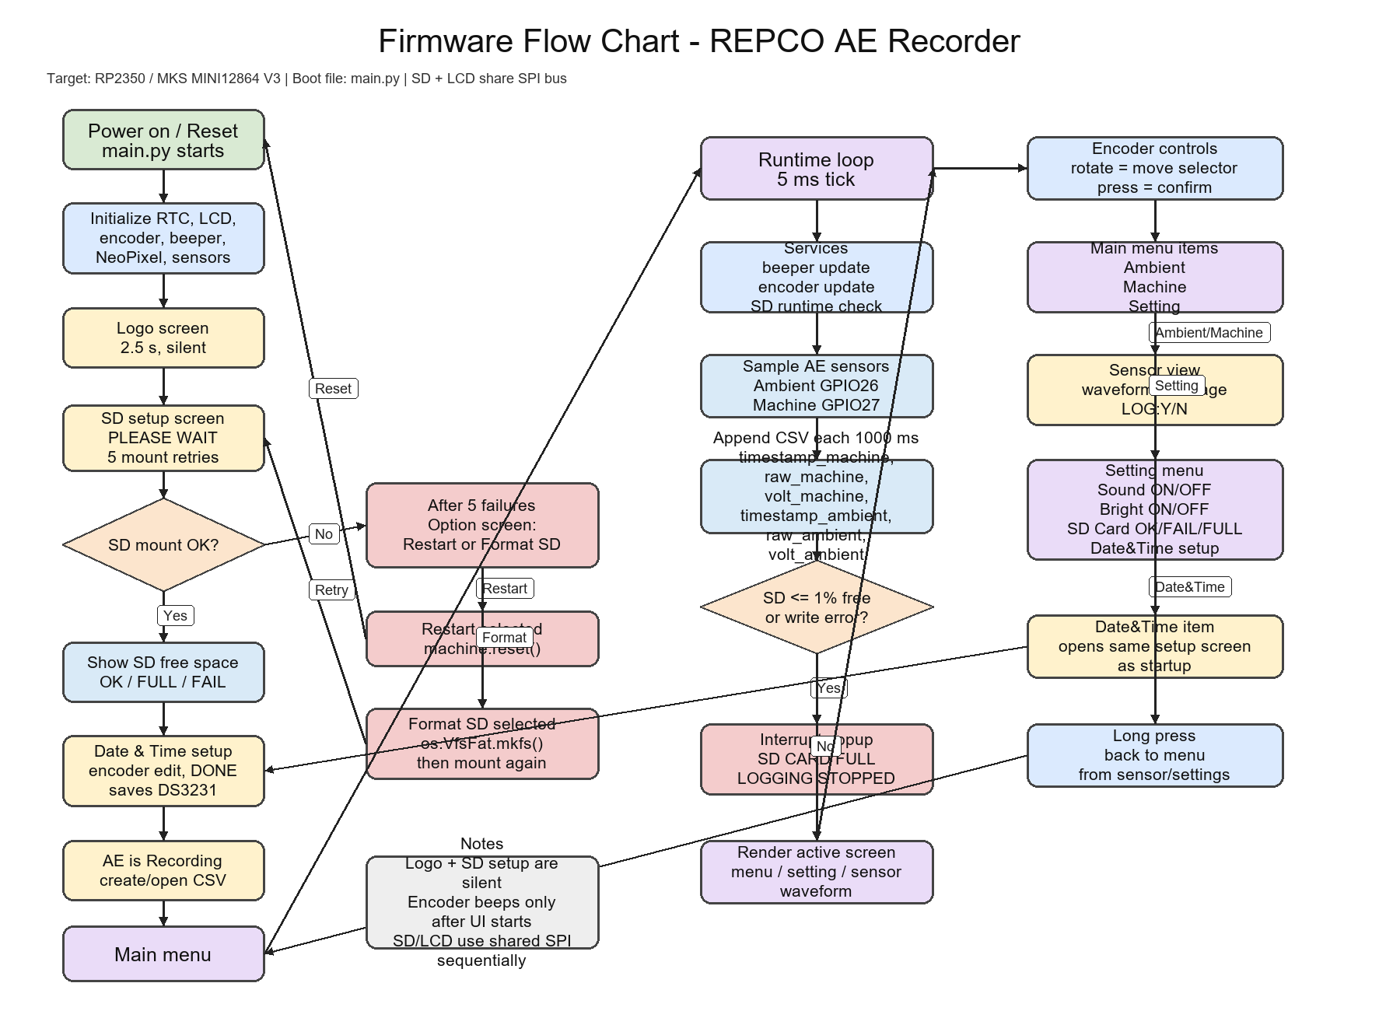
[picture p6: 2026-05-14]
Firmware/firmware_flow_chart.png

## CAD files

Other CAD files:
Design Package Model/Base v1.2.f3d
Design Package Model/Middle Base V1.2.f3d
Design Package Model/UPPER BASE v1.2.f3d
Design Package Model/kick stand.f3d
Design Package Model/metal plate swap.f3d

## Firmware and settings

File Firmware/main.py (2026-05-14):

# main.py - Main loop only

import time
try:
    from enum import Enum
except ImportError:
    class Enum:
        pass
import micropython
micropython.alloc_emergency_exception_buf(200)
import os
import machine

import config
import lcd_mod    as LCD
import rtc_mod    as RTC
import beeper_mod as BEEPER
import encoder_mod as ENC
import neopixel_mod as NEO
import preamp_mod as PREAMP
import logo_mod   as LOGO

class Mode(Enum):
    MENU = 1
    SETTING = 2
    SENSOR = 3

class App:
    AE_LOG_INTERVAL_MS = getattr(config, "AE_LOG_INTERVAL_MS", 1000)
    AE_LOG_FILE = getattr(config, "AE_LOG_FILE", "/sd/ae_record.csv")
    SD_STATUS_CHECK_MS = getattr(config, "SD_STATUS_CHECK_MS", 5000)
    SD_FULL_PERCENT = getattr(config, "SD_FULL_PERCENT", 1)

    def __init__(self):
        # -- hardware and module setup --
        RTC.rtc_init()
        LOGO.show(LCD.lcd, LCD.lcd_update, 2500)
        self.sd_status = "FAIL"
        self.fs_ok = self.show_sd_free_space(restart_on_fail=True)
        self.sd_full_latched = self.sd_status == "FULL"
        self.sd_popup_until = 0
        self.last_sd_check_t = time.ticks_ms()
        self.show_datetime_setup()
        self.recording_ok = False
        self.last_log_t = time.ticks_ms()

        # -- sensor mapping --
        self.SENSOR_MAP = {
            'Ambient': 'AE01',
            'Machine': 'AE02'
        }

        # -- menu page state --
        self.menu = ['Ambient', 'Machine', 'Setting']
        self.menu_sel = 0
        self.menu_top = 0
        self.VISIBLE_MENU_ITEMS = 3

        # -- setting page state --
        self.setting = ['Sound', 'Bright', 'SD Card', 'Date&Time']
        self.setting_sel = 0
        self.setting_top = 0
        self.VISIBLE_SETTING_ITEMS = 5

        # -- application state --
        self.mode = Mode.MENU
        self.page = 0
        self.active_sensor = None

        self.start_ae_recording()
        self.draw_menu()

    def show_datetime_setup(self):
        try:
            RTC.rtc_init()
        except Exception as e:
            print("Date/time setup error:", e)

        values = [2026, 1, 1, 0, 0, 0]
        if getattr(RTC, "rtc_ok", False):
            try:
                t = RTC.get_datetime()
                values = [t[0], t[1], t[2], t[4], t[5], t[6]]
            except Exception as e:
                print("RTC read for setup failed:", e)

        labels = ("Y", "M", "D", "h", "m", "s")
        mins = (2000, 1, 1, 0, 0, 0)
        maxs = (2099, 12, 31, 23, 59, 59)
        sel = 0
        editing = False
        edit_field = 0
        dirty = True
        last_draw = 0

        while True:
            try:
                BEEPER.beep_update()
                ENC.update()

                d = ENC.pop_delta()
                if d:
                    if editing:
                        values[edit_field] += d
                        if values[edit_field] < mins[edit_field]:
                            values[edit_field] = maxs[edit_field]
                        elif values[edit_field] > maxs[edit_field]:
                            values[edit_field] = mins[edit_field]
                        BEEPER.beep_start(3200, 40)
                    else:
                        sel = (sel + d) % 3
                        BEEPER.beep_start(3200, 40)
                    dirty = True

                if ENC.pop_pressed():
                    if editing:
                        if edit_field in (2, 5):
                            editing = False
                        else:
                            edit_field += 1
                        BEEPER.beep_start(900, 60, BEEPER.PRESS_DUTY)
                    elif sel == 0:
                        editing = True
                        edit_field = 0
                        BEEPER.beep_start(900, 60, BEEPER.PRESS_DUTY)
                    elif sel == 1:
                        editing = True
                        edit_field = 3
                        BEEPER.beep_start(900, 60, BEEPER.PRESS_DUTY)
                    else:
                        if RTC.set_datetime(values[0], values[1], values[2], values[3], values[4], values[5]):
                            self.draw_sd_status("DATE TIME SAVED", "DONE")
                        else:
                            self.draw_sd_status("RTC SET FAIL", getattr(RTC, "rtc_status_text", ""))
                        time.sleep_ms(config.DONE_HOLD_MS)
                        break
                    dirty = True

                now = time.ticks_ms()
                if dirty or time.ticks_diff(now, last_draw) >= 300:
                    LCD.spi_to_lcd_speed()
                    LCD.lcd.fill(0)
                    LCD.lcd.text("DATE TIME SETUP", 0, 0)
                    LCD.lcd.text("----------------", 0, 10)

                    date_text = "{:04d}-{:02d}-{:02d}".format(values[0], values[1], values[2])
                    time_text = "{:02d}:{:02d}:{:02d}".format(values[3], values[4], values[5])
                    LCD.lcd.text((">" if sel == 0 else " ") + date_text, 0, 22)
                    LCD.lcd.text((">" if sel == 1 else " ") + time_text, 0, 34)

                    if editing:
                        LCD.lcd.text("EDIT {} {}".format(labels[edit_field], values[edit_field])[:16], 0, 52)
                    else:
                        LCD.lcd.text((">" if sel == 2 else " ") + "DONE", 0, 52)
                    LCD.lcd_update()
                    last_draw = now
                    dirty = False
                time.sleep_ms(10)
            except KeyboardInterrupt:
                raise
            except Exception as e:
                print("Date/time setup loop error:", e)
                break

    def show_sd_free_space(self, restart_on_fail=True):
        ok = False
        mounted = False
        text = "SD: FAIL"
        detail = ""
        self.sd_status = "FAIL"

        try:
            import sd_utils
            self.draw_sd_status("SD SETUP", "PLEASE WAIT")
            time.sleep_ms(config.SD_BOOT_DELAY_MS)
            for attempt in range(config.SD_MOUNT_RETRIES):
                if sd_utils.mount_sd(LCD.spi):
                    mounted = True
                    s = os.statvfs("/sd")
                    free_kb = (s[0] * s[3]) // 1024
                    total_kb = (s[0] * s[2]) // 1024
                    if total_kb > 0:
                        percent = (free_kb * 100) // total_kb
                        if percent <= self.SD_FULL_PERCENT:
                            text = "SD CARD FULL"
                            detail = "FREE: {}%".format(percent)
                            self.sd_status = "FULL"
                        else:
                            text = "SD CARD OK"
                            detail = "FREE: {}%".format(percent)
                            self.sd_status = "OK"
                            ok = True
                    else:
                        text = "SD CARD OK"
                        detail = "FREE: N/A"
                        self.sd_status = "OK"
                        ok = True
                    break
                detail = getattr(sd_utils, "last_error", "")
                print("SD mount retry:", attempt + 1, detail)
                self.draw_sd_status("SD SETUP {}/{}".format(attempt + 1, config.SD_MOUNT_RETRIES), detail)
                time.sleep_ms(config.SD_FRAME_HOLD_MS)
                time.sleep_ms(config.SD_RETRY_DELAY_MS)
        except Exception as e:
            print("SD status error:", e)
            text = "SD: FAIL"
            detail = str(e)
            self.sd_status = "FAIL"
        finally:
            try:
                LCD.spi_to_lcd_speed()
                LCD.lcd.fill(0)
                LCD.lcd.text("SD FREE SPACE", 6, 12)
                LCD.lcd.text("----------------", 0, 24)
                LCD.lcd.text(text, 20, 38)
                if detail:
                    LCD.lcd.text(detail[:16], 0, 52)
                LCD.lcd_update()
                time.sleep_ms(config.SD_FRAME_HOLD_MS)
            except Exception as e:
                print("SD screen error:", e)

        if not mounted and restart_on_fail:
            return self.show_sd_fail_options()

        return ok

    def show_sd_fail_options(self):
        sel = 0
        dirty = True

        while True:
            try:
                BEEPER.beep_update()
                ENC.update()

                d = ENC.pop_delta()
                if d:
                    sel = (sel + d) % 2
                    dirty = True
                    BEEPER.beep_start(3200, 40)

                if ENC.pop_pressed():
                    BEEPER.beep_start(900, 60, BEEPER.PRESS_DUTY)
                    if sel == 0:
                        self.draw_sd_status("RESTARTING", "")
                        time.sleep_ms(config.DONE_HOLD_MS)
                        machine.reset()

                    self.draw_sd_status("FORMAT SD", "PLEASE WAIT")
                    time.sleep_ms(config.DONE_HOLD_MS)
                    try:
                        import sd_utils
                        if sd_utils.format_sd(LCD.spi):
                            self.draw_sd_status("FORMAT OK", "MOUNTING")
                            time.sleep_ms(config.DONE_HOLD_MS)
                            return self.show_sd_free_space(restart_on_fail=False)
                        self.draw_sd_status("FORMAT FAIL", getattr(sd_utils, "last_error", ""))
                    except Exception as e:
                        self.draw_sd_status("FORMAT FAIL", str(e))
                    time.sleep_ms(config.SD_FRAME_HOLD_MS)
                    dirty = True

                if dirty:
                    LCD.spi_to_lcd_speed()
                    LCD.lcd.fill(0)
                    LCD.lcd.text("SD SETUP FAIL", 0, 0)
                    LCD.lcd.text("----------------", 0, 10)
                    LCD.lcd.text((">" if sel == 0 else " ") + "Restart", 0, 28)
                    LCD.lcd.text((">" if sel == 1 else " ") + "Format SD", 0, 42)
                    LCD.lcd_update()
                    dirty = False
                time.sleep_ms(10)
            except KeyboardInterrupt:
                raise
            except Exception as e:
                print("SD fail option error:", e)
                self.draw_sd_status("SYSTEM ERROR", "SD OPTION")
                time.sleep_ms(config.SD_FRAME_HOLD_MS)
                machine.reset()

    def draw_sd_status(self, line1, line2=""):
        try:
            LCD.spi_to_lcd_speed()
            LCD.lcd.fill(0)
            LCD.lcd.text(line1[:16], 0, 18)
            if line2:
                LCD.lcd.text(line2[:16], 0, 34)
            LCD.lcd_update()
        except Exception as e:
            print("SD status draw error:", e)

    def draw_sd_full_popup(self):
        try:
            LCD.spi_to_lcd_speed()
            LCD.lcd.fill(0)
            LCD.lcd.text("SD CARD FULL", 14, 18)
            LCD.lcd.text("LOGGING STOPPED", 0, 34)
            LCD.lcd_update()
        except Exception as e:
            print("SD full popup error:", e)

    def show_recording_screen(self, line2=""):
        try:
            LCD.spi_to_lcd_speed()
            LCD.lcd.fill(0)
            LCD.lcd.text("AE is Recording", 0, 20)
            if line2:
                LCD.lcd.text(line2[:16], 0, 38)
            LCD.lcd_update()
            time.sleep_ms(config.SD_FRAME_HOLD_MS)
        except Exception as e:
            print("Recording screen error:", e)

    def start_ae_recording(self):
        self.recording_ok = False
        if not self.fs_ok:
            return False

        try:
            try:
                os.stat(self.AE_LOG_FILE)
                new_file = False
            except OSError:
                new_file = True

            with open(self.AE_LOG_FILE, "a") as f:
                if new_file:
                    f.write("timestamp_machine,raw_machine,volt_machine,timestamp_ambient,raw_ambient,volt_ambient\n")
            self.recording_ok = True
            self.show_recording_screen()
            return True
        except OSError as e:
            print("AE recording start error:", e)
            self.handle_sd_write_error(e)
            return False

    def handle_sd_write_error(self, err):
        print("SD write error:", err)
        self.sd_status = "FULL"
        self.fs_ok = False
        self.recording_ok = False
        self.sd_full_latched = True
        self.sd_popup_until = time.ticks_add(time.ticks_ms(), config.SD_FRAME_HOLD_MS)
        BEEPER.beep_start(500, 180, BEEPER.PRESS_DUTY)

    def log_ae_row(self, now):
        if (not self.recording_ok) or (not self.fs_ok):
            return
        if time.ticks_diff(now, self.last_log_t) < self.AE_LOG_INTERVAL_MS:
            return
        self.last_log_t = now

        try:
            machine_sensor = PREAMP.sensors["AE02"]
            ambient_sensor = PREAMP.sensors["AE01"]
            raw_machine = machine_sensor._latest
            raw_ambient = ambient_sensor._latest
            volt_machine = machine_sensor.raw_to_v(raw_machine)
            volt_ambient = ambient_sensor.raw_to_v(raw_ambient)
            ts_machine = RTC.time_string()
            ts_ambient = ts_machine

            with open(self.AE_LOG_FILE, "a") as f:
                f.write("{},{},{:.4f},{},{},{:.4f}\n".format(
                    ts_machine,
                    raw_machine,
                    volt_machine,
                    ts_ambient,
                    raw_ambient,
                    volt_ambient
                ))
        except OSError as e:
            self.handle_sd_write_error(e)
        except Exception as e:
            print("AE log error:", e)

    def update_sd_runtime_status(self, now):
        if not self.fs_ok:
            return
        if time.ticks_diff(now, self.last_sd_check_t) < self.SD_STATUS_CHECK_MS:
            return
        self.last_sd_check_t = now

        try:
            s = os.statvfs("/sd")
            free_kb = (s[0] * s[3]) // 1024
            total_kb = (s[0] * s[2]) // 1024
            if total_kb > 0:
                percent = (free_kb * 100) // total_kb
                if percent <= self.SD_FULL_PERCENT:
                    self.sd_status = "FULL"
                    self.fs_ok = False
                    self.recording_ok = False
                    if not self.sd_full_latched:
                        self.sd_full_latched = True
                        self.sd_popup_until = time.ticks_add(now, config.SD_FRAME_HOLD_MS)
                        BEEPER.beep_start(500, 180, BEEPER.PRESS_DUTY)
                else:
                    self.sd_status = "OK"
                    self.sd_full_latched = False
        except OSError as e:
            print("SD runtime status error:", e)
            self.sd_status = "FAIL"
            self.fs_ok = False
            self.recording_ok = False

    def _sync_menu_window(self):
        if self.menu_sel < self.menu_top:
            self.menu_top = self.menu_sel
        elif self.menu_sel >= self.menu_top + self.VISIBLE_MENU_ITEMS:
            self.menu_top = self.menu_sel - self.VISIBLE_MENU_ITEMS + 1

    def _sync_setting_window(self):
        if self.setting_sel < self.setting_top:
            self.setting_top = self.setting_sel
        elif self.setting_sel >= self.setting_top + self.VISIBLE_SETTING_ITEMS:
            self.setting_top = self.setting_sel - self.VISIBLE_SETTING_ITEMS + 1

    def draw_menu(self):
        self._sync_menu_window()
        LCD.lcd.fill(0)
        LCD.lcd.text(RTC.time_hms(), 0, 0)
        LCD.lcd.text("----------------", 0, 10)

        for row in range(self.VISIBLE_MENU_ITEMS):
            i = self.menu_top + row
            if i >= len(self.menu):
                break
            prefix = ">" if i == self.menu_sel else " "
            LCD.lcd.text(prefix + self.menu[i], 0, 22 + row * 10)

        LCD.lcd_update()

    def draw_setting(self):
        self._sync_setting_window()
        LCD.lcd.fill(0)
        LCD.lcd.text('Setting', 0, 0)
        LCD.lcd.text("----------------", 0, 10)
        
        for row in range(self.VISIBLE_SETTING_ITEMS):
            i = self.setting_top + row
            if i >= len(self.setting):
                break
            prefix = ">" if i == self.setting_sel else " "
            LCD.lcd.text(prefix + self.setting[i], 0, 22 + row * 10)
            if i == 0:
                LCD.lcd.text("ON" if BEEPER.is_enabled() else "OFF", 104, 22 + row * 10)
            elif i == 1:
                LCD.lcd.text("ON" if NEO.is_enabled() else "OFF", 104, 22 + row * 10)
            elif i == 2:
                LCD.lcd.text(self.sd_status, 88, 22 + row * 10)

        LCD.lcd_update()

    def enter_sensor(self, sensor_type):
        try:
            sensor_name = self.SENSOR_MAP[sensor_type]
            self.active_sensor = PREAMP.sensors[sensor_name]
            self.active_sensor.init()
            self.mode = Mode.SENSOR
            return True
        except Exception as e:
            print("Sensor init error:", e)
            self.active_sensor = None
            self.mode = Mode.MENU
            return False

    def run(self):
        while True:
            try:
                now = time.ticks_ms()

                # -- services --
                BEEPER.beep_update()
                ENC.update()
                self.update_sd_runtime_status(now)
                self.log_ae_row(now)

                # -- sampling (safe) --
                for sensor in PREAMP.sensors.values():
                    try:
                        if sensor.sample_due(now):
                            sensor.update_sample_time(now)
                            sensor.read_and_add()
                    except Exception as e:
                        print("Sensor error:", e)

                # -- encoder rotation --
                d = ENC.pop_delta()
                if d != 0:
                    if self.mode == Mode.MENU:
                        self.menu_sel = (self.menu_sel + d) % len(self.menu)
                        BEEPER.beep_start(3200, 60)
                    elif self.mode == Mode.SETTING:
                        self.setting_sel = (self.setting_sel + d) % len(self.setting)
                        BEEPER.beep_start(3200, 60)

                # -- button press --
                if ENC.pop_pressed():
                    if self.mode == Mode.MENU:
                        selected = self.menu[self.menu_sel]
                        self.page = self.menu_sel
                        if selected in self.SENSOR_MAP:
                            self.enter_sensor(selected)
                        else:
                            self.mode = Mode.SETTING
                        BEEPER.beep_start(900, 60, BEEPER.PRESS_DUTY)
                    elif self.mode == Mode.SETTING:
                        if self.setting_sel == 0:
                            BEEPER.set_enabled(not BEEPER.is_enabled())
                            if BEEPER.is_enabled():
                                BEEPER.beep_start(900, 60, BEEPER.PRESS_DUTY)
                        elif self.setting_sel == 1:
                            NEO.toggle()
                            BEEPER.beep_start(900, 60, BEEPER.PRESS_DUTY)
                        elif self.setting_sel == 2:
                            pass
                        elif self.setting_sel == 3:
                            BEEPER.beep_start(900, 60, BEEPER.PRESS_DUTY)
                            self.show_datetime_setup()
                            self.mode = Mode.SETTING
                        else:
                            print("Setting item:", self.setting[self.setting_sel])
                            BEEPER.beep_start(900, 60, BEEPER.PRESS_DUTY)
                    elif self.mode == Mode.SENSOR:
                        self.enter_sensor(self.menu[self.page])
                        BEEPER.beep_start(900, 60, BEEPER.PRESS_DUTY)

                # -- button long press --
                if ENC.pop_long():
                    if self.mode == Mode.SENSOR:
                        self.mode = Mode.MENU
                        self.active_sensor = None
                        LCD.lcd.fill(0)
                    elif self.mode == Mode.SETTING:
                        self.mode = Mode.MENU
                    BEEPER.beep_start(500, 100)

                # -- rendering --
                try:
                    if time.ticks_diff(self.sd_popup_until, now) > 0:
                        self.draw_sd_full_popup()
                    elif self.mode == Mode.MENU:
                        self.draw_menu()
                    elif self.mode == Mode.SETTING:
                        self.draw_setting()
                    elif self.mode == Mode.SENSOR:
                        if self.active_sensor is not None:
                            self.active_sensor.draw_screen(log_enabled=self.fs_ok)
                except OSError as e:
                    print("FS error:", e)
                    self.fs_ok = False
                    self.mode = Mode.MENU
                    self.active_sensor = None
                    LCD.lcd.fill(0)
                    LCD.lcd.text("filesystem error", 0, 0)
                    LCD.lcd.text("Contact: 0XXXXXXXXX", 0, 10)
                    LCD.lcd_update()
                except Exception as e:
                    print("Render error:", e)
                    self.mode = Mode.MENU
                    self.active_sensor = None
            
            except KeyboardInterrupt:
                print("User interrupt (Ctrl+C)")
                try:
                    self.active_sensor = None
                    LCD.lcd.fill(0)
                    LCD.lcd.text("STOPPED", 0, 0)
                    LCD.lcd.text("Contact: 0XXXXXXXXX", 0, 10)
                    LCD.lcd_update()
                except:
                    pass
                break
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

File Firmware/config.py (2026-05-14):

# config.py - PIN and hardware constants
#
# Hardware:
# - Controller: Cytron MOTION 2350 Pro / RP2350
# - Peripheral: MKS MINI12864 V3 on shared SPI
#
# MKS MINI12864 V3 has an ST7567 LCD and onboard SD slot on the same SPI bus.
# The LCD and SD card must never have CS low at the same time.

PIN_NEOPIXEL    = 4
PIN_BEEPER      = 0
PIN_ENC_A       = 5
PIN_ENC_B       = 6
PIN_ENC_BTN     = 7

PIN_LCD_CS      = 2
PIN_LCD_DC      = 3
PIN_LCD_RST     = 1

# Shared SPI0 wiring from MOTION 2350 Pro GPIO header to MKS MINI12864 V3.
PIN_SPI_SCK     = 18
PIN_SPI_MOSI    = 19
PIN_SPI_MISO    = 16
PIN_SD_CS       = 17

PIN_AE_SENSOR02_ADC = 27
PIN_AE_SENSOR01_ADC = 26
PIN_RTC_SDA     = 28
PIN_RTC_SCL     = 29

LCD_BAUD = 2000000
SD_BAUD  = 25000
LCD_SPI_POLARITY = 1
LCD_SPI_PHASE    = 1
SD_SPI_POLARITY  = 1
SD_SPI_PHASE     = 1
SD_PARTITION_LBA = 32
SD_BOOT_DELAY_MS = 3000
SD_MOUNT_RETRIES = 5
SD_RETRY_DELAY_MS = 700
SD_CMD9_RETRIES = 5
SD_FRAME_HOLD_MS = 2500
SD_STATUS_CHECK_MS = 5000
SD_FULL_PERCENT = 1
DONE_HOLD_MS = 1200
AE_LOG_INTERVAL_MS = 1000
AE_LOG_FILE = "/sd/ae_record.csv"
VREF     = 3.3

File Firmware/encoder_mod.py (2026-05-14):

# encoder_mod.py - Rotary encoder with debounce

from machine import Pin
import time
import config

enc_a = Pin(config.PIN_ENC_A, Pin.IN, Pin.PULL_UP)
enc_b = Pin(config.PIN_ENC_B, Pin.IN, Pin.PULL_UP)
btn   = Pin(config.PIN_ENC_BTN, Pin.IN, Pin.PULL_UP)

TRANS = {
    (0, 1): +1, (1, 3): +1, (3, 2): +1, (2, 0): +1,
    (0, 2): -1, (2, 3): -1, (3, 1): -1, (1, 0): -1,
}

STEPS_PER_CLICK = 4
DEBOUNCE_MS     = 120
LONG_MS         = 1100
ENC_IGNORE_MS   = 80

_last_state      = (enc_a.value() << 1) | enc_b.value()
_enc_accum       = 0
_last_btn        = btn.value()
_last_btn_t      = time.ticks_ms()
_press_t         = 0
_back_latched    = False
_enc_ignore_until = 0

delta_accum = 0   # +1 or -1 per click, read and clear in main
btn_pressed = False
btn_long    = False

def update():
    global _last_state, _enc_accum, delta_accum
    global _last_btn, _last_btn_t, _press_t, _back_latched
    global _enc_ignore_until, btn_pressed, btn_long

    now = time.ticks_ms()

    # encoder
    if btn.value() == 1 and time.ticks_diff(now, _enc_ignore_until) >= 0:
        s = (enc_a.value() << 1) | enc_b.value()
        if s != _last_state:
            d = TRANS.get((_last_state, s), 0)
            _last_state = s
            if d:
                _enc_accum += d
                if _enc_accum >= STEPS_PER_CLICK:
                    _enc_accum = 0
                    delta_accum += 1
                elif _enc_accum <= -STEPS_PER_CLICK:
                    _enc_accum = 0
                    delta_accum -= 1

    # button
    b = btn.value()
    if b != _last_btn and time.ticks_diff(now, _last_btn_t) > DEBOUNCE_MS:
        _last_btn = b
        _last_btn_t = now
        if b == 0:
            _press_t = now
            _back_latched = False
            _enc_ignore_until = time.ticks_add(now, ENC_IGNORE_MS)
        else:
            if not _back_latched:
                btn_pressed = True

    # long press
    if btn.value() == 0 and not _back_latched:
        if time.ticks_diff(now, _press_t) >= LONG_MS:
            _back_latched = True
            btn_long = True

def pop_delta():
    global delta_accum
    d = delta_accum
    delta_accum = 0
    return d

def pop_pressed():
    global btn_pressed
    p = btn_pressed
    btn_pressed = False
    return p

def pop_long():
    global btn_long
    l = btn_long
    btn_long = False
    return l

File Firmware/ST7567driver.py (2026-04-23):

#Micro Python ST7567 128*64 lcd driver
#You may need to set elecvolt and regratio to drive your screen properly
#
from micropython import const
import framebuf

SET_BIAS  =const(0xA2)
POWER_CTRL=const(0x28)
SET_BOOST =const(0xF8)
SOFT_RST  =const(0xE2)
SEG_DIR   =const(0xA0)
COM_DIR   =const(0xC0)
REGU_RATIO=const(0x20)
EVSET_MODE=const(0x81)
DISP_ONOFF=const(0xAE)
INV_DISP  =const(0xA6)#0:normal display 1:inverse
ALL_PIX_ON=const(0xA4)
SRTLIN_SET=const(0x40)#40~7F
PAGEAD_SET=const(0xB0)#b0~b8
COLHAD_SET=const(0x10)#0x10~0x1F
COLLAD_SET=const(0x00)#0x00~0x0F

class ST7567(framebuf.FrameBuffer):
    def __init__(self,spi,a0,cs=None,rst=None,elecvolt=0x1F,regratio=0x03,invX=False,invY=False,invdisp=False):
        a0.init(a0.OUT,value=0)
        self.a0=a0
        if(cs is not None):
            cs.init(cs.OUT,value=1)#disable device port
            self.cs=cs
        if(rst is not None):
            rst.init(rst.OUT,value=0)#reset device
            self.rst=rst
            import time
            time.sleep_ms(1)
            self.rst.value(1)
            time.sleep_ms(1)
        self.spi=spi
        initCMDList=[
            SOFT_RST,#optional, I think it's useless
            SET_BOOST,#set booster mode
            0x00,#boost: 0x00:x4 0x01:x5
            SET_BIAS|0x01,# 0:1/9 1:1/7
            EVSET_MODE,#put device into EV setting mode
            elecvolt,#0x00~0x3F set contrast to 0x1f with last command
            REGU_RATIO|regratio,#0x00~0x07 3.0~6.5
            POWER_CTRL|0x04,#7:{booster on,regulator on,follower on}
            POWER_CTRL|0x06,
            POWER_CTRL|0x07,
            SEG_DIR|(0x01 if invX else 0x00),#0:MX=0 normal dir, 1:MX=1 reverse dir
            COM_DIR|(0x08 if invY else 0x00),#0x00:MY=0 0x08:MY=1 (may change to reverse y)
            INV_DISP|(0x01 if invdisp else 0x00),#normal display
            SRTLIN_SET|0x00,
            DISP_ONOFF|0x01,
            ALL_PIX_ON|0x00]#0x00:normal display 0x01:all pixel on
        self.buffer=bytearray(128*64//8)
        super().__init__(self.buffer, 128, 64, framebuf.MONO_VLSB)
        self.writeCMD(initCMDList)
        self.fill(0)
        self.show()
        
    def writeCMD(self,cmd):
        self.cs.value(0)#enable device port
        self.a0.value(0)#cmd mode
        self.spi.write(bytearray(cmd))
        self.cs.value(1)#disable device port 
    
    def writeData(self,data):
        self.cs.value(0)#enable device port
        self.a0.value(1)#display data mode
        self.spi.write(data)
        self.cs.value(1)#disable device port

    def show(self):
        self.writeCMD([SRTLIN_SET|0x00])
        for pagcnt in range(8):
            self.writeCMD([PAGEAD_SET|pagcnt,COLHAD_SET|0x00,COLLAD_SET|0x00])
            self.writeData(self.buffer[(128*pagcnt):(128*pagcnt+128)])

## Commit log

2026-05-14 Update section titles and add Design CAD details
2026-05-15 Add design review report for enclosure concept design
    This report documents the progress and updates for the 3D-printed enclosure project across two concept design iterations, detailing issues, modifications, and future development plans.
2026-05-22 Revise Enclosure Concept Design Report with updates
    Updated the enclosure concept design report to include modifications and new components for future development.
